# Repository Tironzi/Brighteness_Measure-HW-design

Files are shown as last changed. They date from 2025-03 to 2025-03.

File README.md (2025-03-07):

# Brighteness_Measure-HW-design
Electronics Applications Project 
Requirements: Design a light measurement circuit using a photodiode. The circuit should have a measurement range of 10-100 mW/cm², with a resolution of 5 mW/cm², and the output should be a corresponding current ranging from 4-20 mA (grounded).

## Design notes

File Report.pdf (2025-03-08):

ĐẠI HỌC QUỐC GIA TP. HỒ CHÍ MINH

TRƯỜNG ĐẠI HỌC BÁCH KHOA

KHOA ĐIỆN – ĐIỆN TỬ

BỘ MÔN ĐIỆN TỬ

---------------o0o---------------

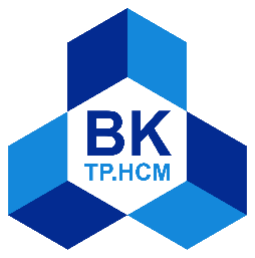
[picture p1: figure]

BÁO CÁO BÀI TẬP LỚN – PHẦN 1

ĐIỆN TỬ ỨNG DỤNG

LỚP L01 – NHÓM 9

ĐỀ TÀI:

THIẾT KẾ MẠCH ĐO ÁNH SÁNG SỬ DỤNG PHOTODIODE

BRIGHTNESS METER CIRCUIT DESIGN

Giảng viên hướng dẫn: Ths. Nguyễn Trung Hiếu

TP. HCM, tháng 12 năm 2024

SINH VIÊN THỰC HIỆN ĐỀ TÀI

Họ và tên | MSSV | Chữ ký
Lê Trung Hiếu | 2111185
Nguyễn Đức Hoàng | 2110184
Lê Viết Trọng | 2012298

LỜI CẢM ƠN

Trước tiên, nhóm chúng em xin gửi lời cảm ơn tới các quý thầy cô Khoa Điện - điện

tử của trường Đại học Bách Khoa Tp.HCM đã chỉ dạy, truyền đạt những kiến thức, kỹ

năng cần thiết để chúng em có thể thực hiện được đề tài này.

Và hơn hết, nhóm chúng em xin gửi lời cảm ơn chân thành đến thầy Nguyễn Trung

Hiếu đã tận tình chỉ dẫn, giúp đỡ chúng em trong quá trình thực hiện đề tài. Những lời

khuyên bổ ích của thầy đã giúp chúng em rất nhiều trong quá trình nghiên cứu đề tài

và giải quyết những vấn đề gặp phải để có thể hoàn thiện đề tài một cách tốt nhất.

Do kiến thức của các thành viên trong nhóm còn hạn chế nên sẽ có những sai sót trong

quá trình thực hiện đề tài. Nhóm em rất mong nhận được sự đánh giá khắt khe và góp

ý từ thầy để chúng em có thể hoàn thiện hơn nữa.

Cuối cùng, nhóm chúng em xin chúc thầy luôn luôn mạnh khỏe và ngày càng thành

công trong công việc ạ!!!

Trân trọng,

GIỚI THIỆU ĐỀ TÀI

Chúng ta có thể thấy trong thế giới ngày nay mọi thức đang dần trở nên số hóa,

mọi thức ngày càng hiện đại và văn minh hơn. Vì vậy nhắc tới thế ngày nay thì luôn

gắn liền với những cụm từ thông minh như nhà thông minh, thành phố thông minh,

máy móc thông minh. Nhưng thứ này sinh ra mục đích là để phục vụ cho đời sống của

con người chúng ta. Những thiết bị điện tử ngày càng tiên tiến và phát triển, chúng tập

trung vào sự chính xác, tốc độ phản hồi nhanh đem đến một trải nghiệm người dùng

hiệu quả, chính xác. Để có được những yêu cầu đó thì cảm biến đóng một vai trò rất

quan trọng trong các thiết bị điện tử. Từ sinh hoạt, sản xuất, hay y tế mọi lĩnh vực trong

cuộc sống này không thể thiếu thiết bị cảm biến. Chúng là hạt nhân trong thế giới hiện

đại. Cảm biến góp phần cho thế giới ngày càng trở nên linh hoạt hơn và tự động hóa

giúp nâng cao năng suất và hiệu quả. Sự xuất hiện của cảm biến đã mở ra vô vàn các

thiết bị ứng dụng vào vô vàn lĩnh vực trong đời sống. Thế nên, nhóm chúng em sẽ giới

thiệu một loại cảm biến thực hiện trong đề tài lần này là cảm biến ánh sáng. Cũng như

các loại cảm biến khác, cảm biến ánh sáng rất quan trọng trong nhiều lĩnh vực. Trong

smart home chúng điều chỉnh tự động ánh sáng trong căn phòng phù hợp với từng điều

kiện cụ thể; trong công nghiệp chúng điều chỉnh độ sáng trong các hệ thống chiếu sáng.

Trong các thiết bị điện tử như điện thoại, máy tính bảng chúng tự điều chỉnh độ sáng

màn hình giúp tiết kiệm pin, bảo vệ mắt. Vì những lợi ích trên mà cảm biến ánh sáng

mang lại nên nhóm chúng em quyết định chọn đề tài “ Thiết kế mạch đo ánh sáng sử

dụng Photodiode ”.

MỤC LỤC

e. Thiết kế mạch đọc dòng điện và cho ngõ ra ADC. Tiến hành lựa chọn ADC a. Lựa chọn và mô phỏng photodide 2 dây (có điện trở dây dẫn là 10Ω).

Để có thể đo thông số EE trong khoảng 10mW/cm² đến 100mW/cm²

, đầu tiên, cần chọn

một photodiode phù hợp. Photodiode SFH 206 K là lựa chọn lý tưởng cho mạch đo cường độ ánh sáng từ 10 mW/cm² đến 100 mW/cm² với độ phân giải 5 mW/cm² nhờ

vào các đặc tính vượt trội như dải nhạy quang phổ rộng (400 nm - 1100 nm), độ nhạy

cao R(λ)=0.62 A/W tại 850 nm, và diện tích nhạy sáng lớn 7.02 mm²
. Với thời gian đáp
ứng nhanh (20 ns) và khả năng hoạt động ổn định trong môi trường từ -40°C đến 100°C,

photodiode này đảm bảo đo chính xác cường độ ánh sáng trong phạm vi yêu cầu, đáp

ứng tốt yêu cầu từ đề tài, cùng với lợi ích đó lại giá thành rẻ.

Để tính được dòng quang điện IP, đầu tiên, chúng ta có được công thức tính Sensitivity

của photodiode như sau:

R(λ) = k ∗ S(λ)

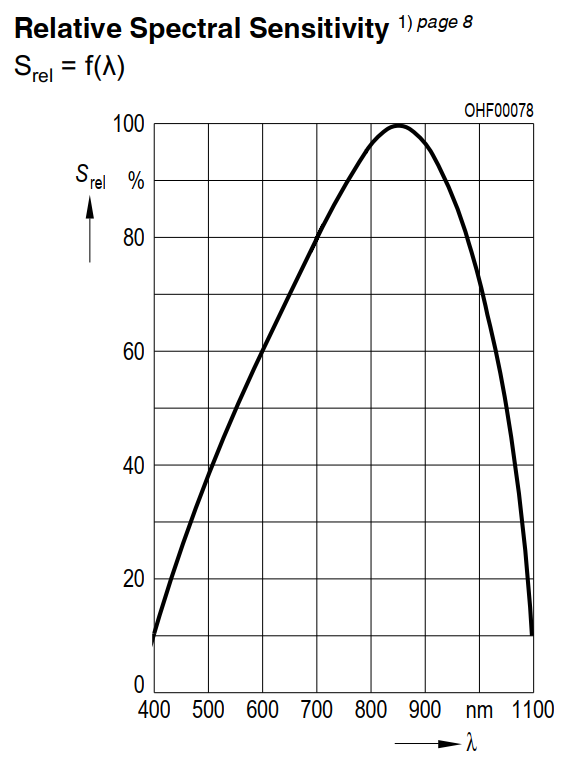
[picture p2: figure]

Dựa vào datasheet, tại λ = 850nm, ta có được R(λ) = 0.62 (A/W) = 0.62 (mA/mW) và S(λ)=1. Như vậy, hằng số k sẽ bằng 0.62. Dựa vào datasheet, lấy chuẩn tại tại λ =

550nm, S(λ)=0.5. Sau khi tính được hệ số k, dòng quang điện IP được tính như sau:

IP = R(λ) ∗ ΦE = k ∗ S(λ) ∗ EE ∗ A = 0.62 ∗ 0.5 ∗ EE ∗ (2.6 ∗ 10⁻¹

∗ 1.09 ∗ 10⁻¹
)
= 8.7854 ∗ 10⁻³
∗ EE(mA)

Do EE nằm trong khoảng 10mW/cm² đến 100mW/cm²

, nên IP sẽ nằm trong khoảng từ

0.087854 (mA) đến 0.87854 (mA). Bên cạnh đó, để tham chiếu, dựa vào khoảng giá trị

của EE, có thể tính được EV nằm trong khoảng 6.83 lm/cm² đến 68.3 lm/cm²

. Tham số

này sẽ có giá trị khi sử dụng các thiết bị Lux Meter để kiểm tra độ chói trong thực tế.

Các giá trị của EE khi đổi sang EV sẽ dựa trên bảng sau:

EE (mW/cm2) | EV (lm/cm2) | EE (mW/cm2) | EV (lm/cm2)
10 | 6.83 | 60 | 40.98
15 | 10.245 | 65 | 44.395
20 | 13.66 | 70 | 47.81
25 | 17.075 | 75 | 51.225
30 | 20.49 | 80 | 54.64
35 | 23.905 | 85 | 58.055
40 | 27.32 | 90 | 61.47
45 | 30.735 | 95 | 64.885
50 | 34.15 | 100 | 68.3

55 37.565

Trong phần mềm Multisim, SFH 206 K sẽ được mô phỏng bằng một diode có 3 cực,

ngoài hai cực Anode và Cathode thì còn có một chân P. Theo như mô tả, Trong mô hình SPICE của photodiode SFH_206_K/AD, chân P đại diện cho đầu vào ánh sáng,

được mô phỏng như một điện áp tỷ lệ với cường độ ánh sáng chiếu tới (W/cm²). Giá

trị điện áp này được sử dụng để tính dòng quang điện IP = V(P) ∗ Spec ∗ Sensy, trong

đó Spec (mặc định bằng 1.0) là thông số quang phổ và Sensy là độ nhạy của

photodiode (mặc định 0.62 A/W). Chân P cũng hỗ trợ mô phỏng các đặc tính động như

rise time và fall time qua các linh kiện R và C. Để có thể mô phỏng giá trị của IP dựa

trên giá trị của V(P) thì tiến thành mô phỏng photodiode trong điều kiện ngắn mạch:

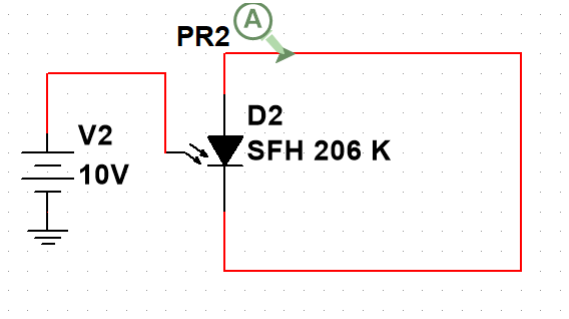
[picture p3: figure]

Khi này, dòng IP sẽ bằng dòng ngắn mạch ISC và bằng dòng từ Anode sang Cathode

IKA. Khi mô phỏng bằng Parameter Sweep cho thông số V(P), khi kiểm tra bảng số liệu

và đồ thị, có thể thấy rằng IP = V(P) ∗ 1.0 ∗ 0.62 và bên cạnh đó, có thể thấy I có giá

trị max bằng 1A khi V(P) đạt khoảng 1.6129 V do hiện tượng bão hòa dòng quang

điện, khi photodiode đã tạo ra và thu thập tối đa các cặp điện tử-lỗ trống từ ánh sáng

chiếu vào.

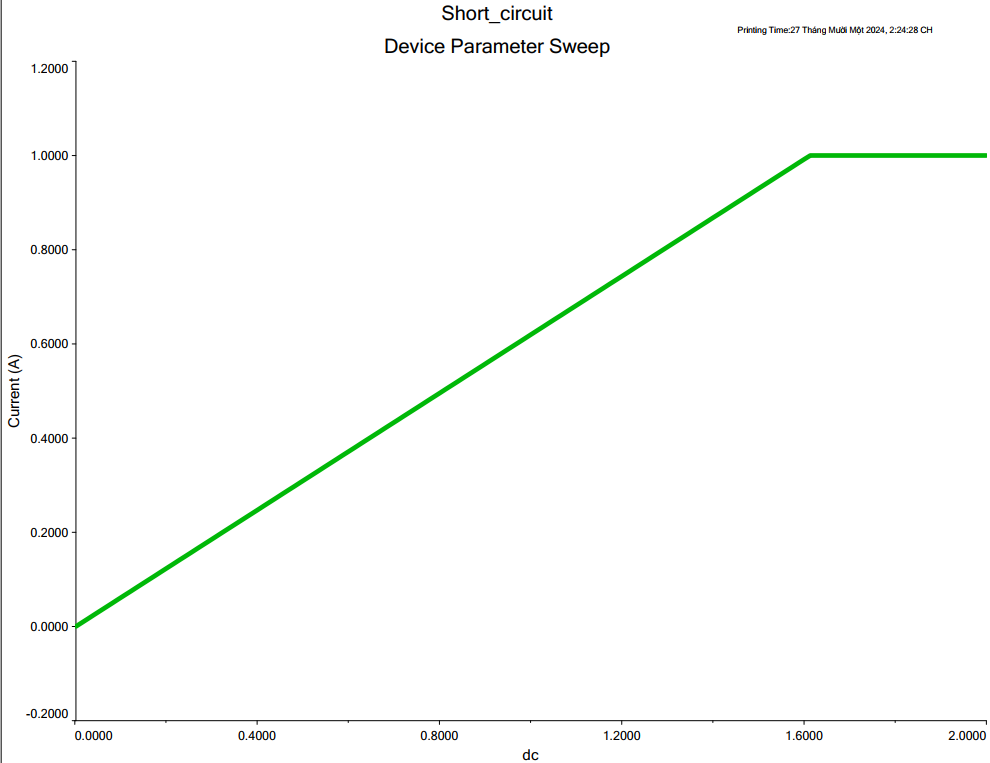
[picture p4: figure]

b. Lựa chọn mode hoạt động của photodiode:

Để giảm thiểu dòng tối của photodiode, ta sẽ vận hành photodiode trong chế độ quang

điện (photovoltaic mode) và sử dụng mạch chuyển đổi dòng sang điện áp như hình

dưới đây.

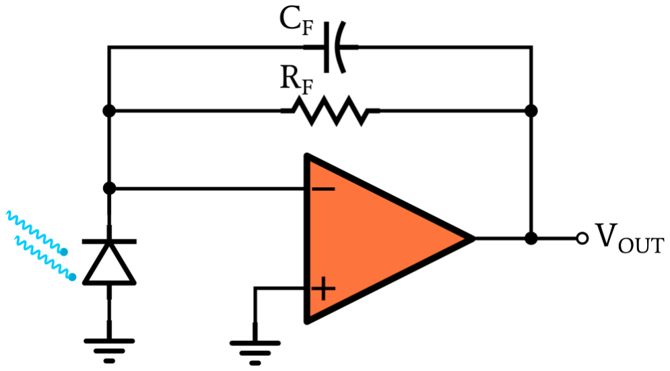
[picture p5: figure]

Như vậy, chúng ta sẽ có công thức tính điện áp DC Vout của mạch như sau:

Vout = IP ∗ RF

Trong đó, chỉ có điện trở hồi tiếp (RF) có tác dụng khuếch đại. Tụ điện (CF) được sử

dụng nhằm tránh hiện tượng dao động bằng cách bù trừ cho điện dung mạch trong của

nút photodiode, vốn tạo ra một cực (pole) trong mạng hồi tiếp. Tụ CF thực hiện bù trừ

bằng cách tạo ra một điểm zero trong mạng hồi tiếp. CF là tụ được mắc thêm để lọc

thông cao với tần số cắt fc =

1
2πRFCF

. Điều này để giảm ảnh hưởng của các điều kiện

không lý tưởng của OP-AMP.

Như vậy, chọn RF = 2.7 kOhm, lúc đó Vout = 2700*IP.

c. Lựa chọn OP-AMP sử dụng, mô phỏng OP-AMP theo datasheet:

OPA333 được chọn nhờ các đặc tính vượt trội: dòng lệch ngõ vào Iio=140 pA, dòng

thiên ngõ vào Iib=70 pA và điện áp bù ngõ vào Vio=2 μV, đảm bảo độ chính xác cao và

phù hợp cho các ứng dụng đo lường chính xác.

Tính toán sai lệch gây ra bởi Vio của OP-AMP:

∆V = ±Vio ∗ (1 +

2700
10 ) = ±540μV

Tính toán sai lệch gây ra bởi Iio và Iib:

Iib =

I+ + I−
2

= 70pA

Iio = |I+ − I−

| = 140pA

I+ = 140pA,I− = 0 ℎoặc I− = 140pA,I+ = 0

∆V = I− ∗ R− = 0.3789(μA)

Mô phỏng OP-AMP OPA333 trong Multisim bằng cách tạo một khối hierarchial

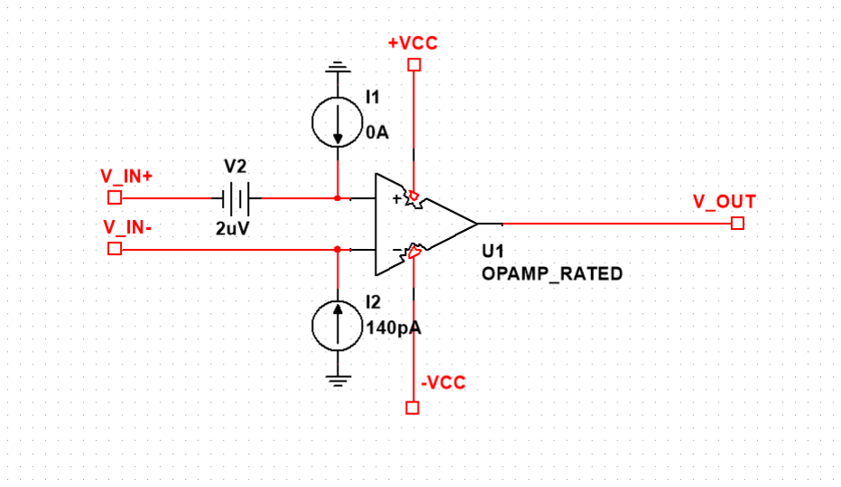
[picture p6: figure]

d. Đảm bảo sai số (giữa giá trị lý thuyết và giá trị thực tế) dưới ±5%:

Để kiểm tra Vout giữa tính toán lý thuyết và giá trị thực tế khi mô phỏng, cần lập một bảng

Excel để khảo sát giá trị phụ thuộc vào Irradiance EE:

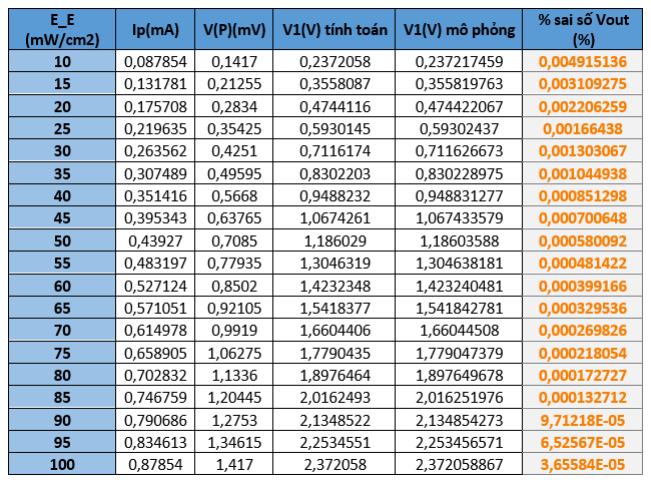
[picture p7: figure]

Với IP được tính bằng công thức đã được trình bày trong câu a, V(P) = IP/0.62, V1 theo lý

thuyết sẽ được tính bằng V1_lt=IP*2700. Giá trị V1 sẽ được mô phỏng sẽ được mô phỏng

bằng phần mềm Multisim. Sai số sẽ được tính như sau:

% sai số =

|V1 lý tℎuyết − V1 mô pℎỏng |

V1 lý tℎuyết

∗ 100%

Như vậy, dựa trên mô phỏng, sai số dưới 5% được đảm bảo.

e. Thiết kế mạch đọc dòng điện và cho ngõ ra ADC. Tiến hành lựa chọn ADC (số bit,

nguồn). Mô phỏng mạch đọc và kiểm chứng.

Đầu tiên, cần thiết kế mạch chuyển đổi từ điện áp V1 từ 0,2372058-2,372058 V sang

4-20 mA. Xây dựng phương được phương trình Iout theo V1 như sau:

Iout = 0.007494664033V1 +

1
450 (1)

Sử dụng mô hình mạch V/I:

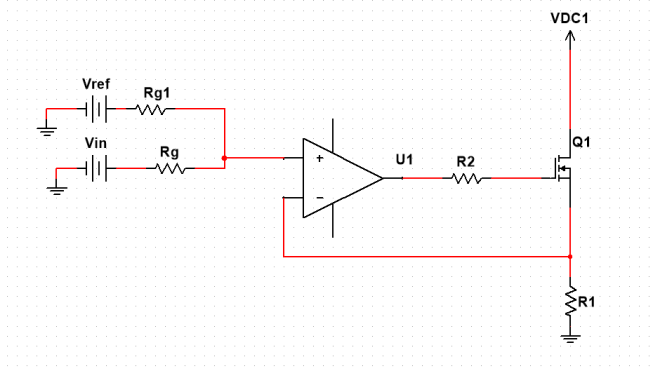
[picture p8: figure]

Iout = IR1 =

V1 + Vref
2R1

(2)

Từ (1) và (2) => Chọn R1 = 66.7 Ohm, Vref = 0.2695 V, R2 = 10 Ohm, Rg = 1kOhm. Tiến hành mô phỏng và kiểm chứng mạch:

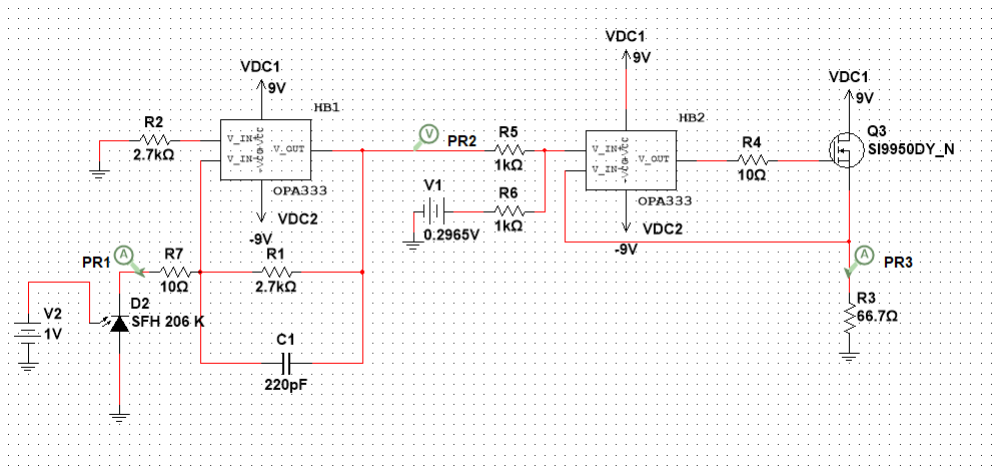
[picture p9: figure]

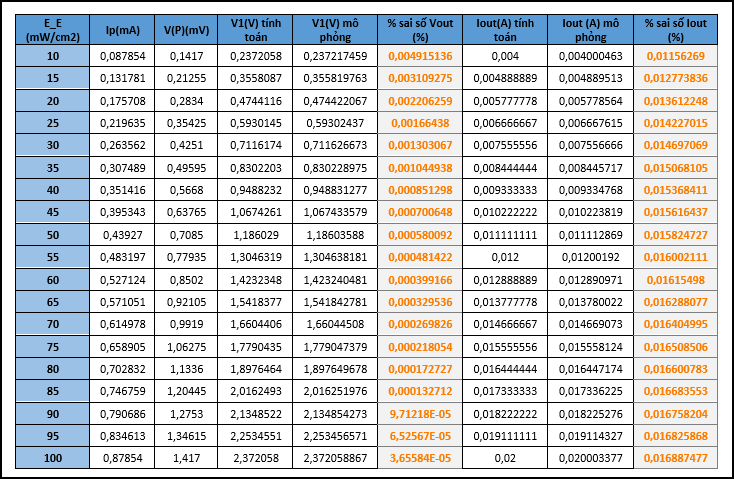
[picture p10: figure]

Biểu đồ phía trên thể hiện mối quan hệ giữa V(P) (trục hoành) và V1 (đường màu xanh

dương), Iout (đường màu xanh lá).

Thiết kế mạch đọc ADC:

Đầu tiên, để có thể đọc tín hiệu dòng điện, cần thiết kế mạch sử dụng AD8237RMZ để

khuếch đại giá trị dòng đi qua điện trở 66.7 Ohm như sau:

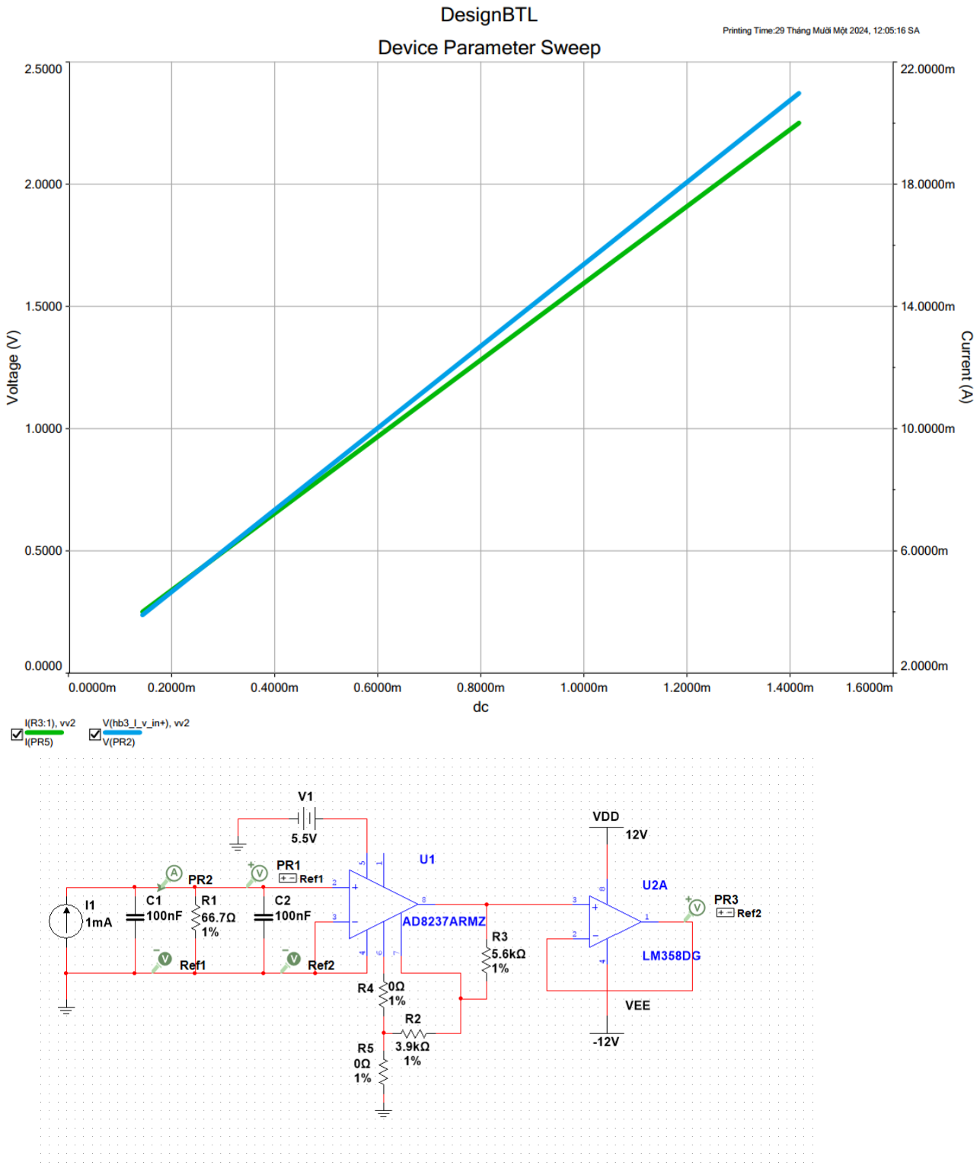
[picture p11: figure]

Như vậy, khi đi qua AD8237, Vout sẽ bằng I1 ∗ R1 ∗ (1 +
R3
R2

) = I1 ∗ 162.4736

Tiếp theo đó, cần thêm một voltage follower (hoặc buffer amplifier) trước khi đưa tín

hiệu vào ADC (Analog-to-Digital Converter) là rất quan trọng trong nhiều trường hợp

để đảm bảo tín hiệu được đo chính xác và không bị suy giảm. Đầu tiên, nó cải thiện

impedance matching, đặc biệt khi nguồn tín hiệu có impedance cao, bằng cách sử

dụng impedance đầu vào cao và impedance đầu ra thấp, giúp tránh suy giảm tín hiệu

và đảm bảo tín hiệu vào ADC không bị mất mát. Thứ hai, voltage follower giảm tải lên

nguồn tín hiệu, ngăn ngừa hiện tượng tải quá mức bởi ADC, do ADC thường có dòng

tải khá lớn ở đầu vào. Ngoài ra, voltage follower duy trì tín hiệu không biến dạng, đặc

biệt khi sử dụng với operational amplifier (op-amp), giúp giữ tín hiệu đầu vào chính

xác khi đọc qua ADC. Nó cũng giúp giảm thiểu ảnh hưởng của dòng tải, bảo vệ tín hiệu

gốc và giúp ADC nhận tín hiệu ổn định hơn. Cuối cùng, trong trường hợp tín hiệu gốc

có biên độ thấp, voltage follower giúp tăng cường tín hiệu sao cho phù hợp với phạm

vi của ADC, tăng độ chính xác và độ phân giải của phép đo.

Như vậy, sau khi gắn thêm voltage follower tại V1 (điện áp sau khi qua AD8237), mạch

đo ADC được thiết kế như sau:

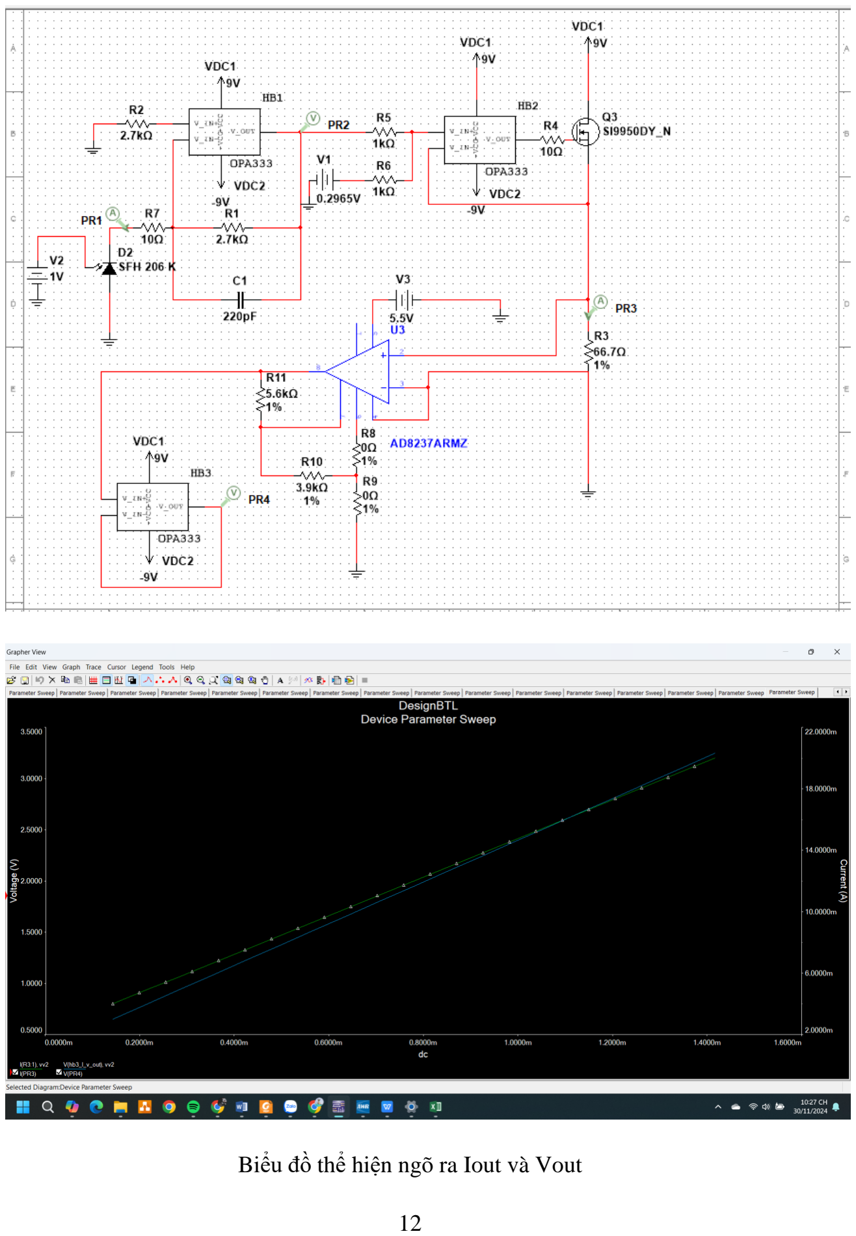
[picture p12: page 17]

Biểu đồ thể hiện ngõ ra Iout và Vout

Chọn 12 bit ADC để phù hợp với STM32. Với mức điện áp tham chiếu 3.3V, công

thức để chuyển đổi thành giá trị digital 12-bit như sau:

Digital = (

Điện áp đầu vào(V)
3.3(V)

) ∗ 4096

Như vậy, có bảng giá trị quy đổi dựa vào Vout mô phỏng như sau:

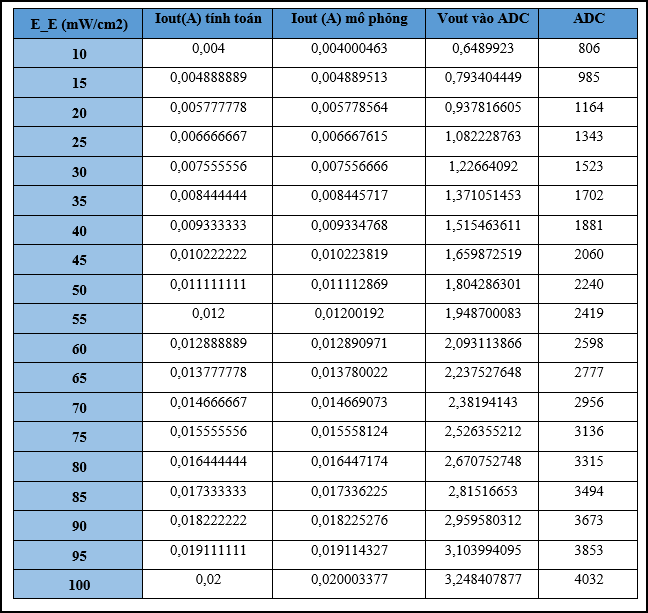
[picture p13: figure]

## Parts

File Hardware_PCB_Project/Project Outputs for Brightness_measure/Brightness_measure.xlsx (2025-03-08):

Comment | Description | Designator | Footprint | LibRef | Quantity
Test_Point | Test point, 2mm radius | -9V, +0.2965V, +5V, +9V, +12V, GND, V1, Vtrim | TP_2MM | Test_Point | 8 | v
10uF | CAP, size 0603,10uF | C1, C3 | CAP_0603 | 01060310010 | 2 | v
100nF | CAP, size 0603, 100nF | C2, C4, C9 | CAP_0603 | 01060310410 | 3 | v
22uF | V-Chip, D4 x H5.5mm, 22uF, 16V | C5 | WCAP-ASLI_D4H5.5 | 865080340003 | 1 | v
10uF | Dán | C6, C10 | tu nhom 4 (b) | Tu Nhom 10uF 16V | 2 | 5 | ic
1uF | CAP, size 0603, 1uF | C7, C8 | CAP_0603 | 01060310510 | 2 | v
220pF | Dán | C11 | Tu 0603 | Tu 0603 220pF 50V 10% | 1 | 10 | ic
D Schottky | Schottky Diode | D1 | SS34 | D Schottky | 1 | v
LED SMD | LED | D2, D3, D4 | LED_0805_Blue | LED SMD | 3 | 10 | ic
SFH206K | photodiode, 850nm | D5 | SFH206K | SFH206K | 1 | v
16V, 2.5A | Resettable Fuse, Size 1812, 8V, 2A | F1 | Fuse_SMD_1812 | 061812200008 | 1 | 1 | ic
Jac DC | Jac DC input | JDC1 | DC0 | DCIN | 1 | v
LN2302LT1G | SOT-23-3, MOSFET kênh N, 20V, 2.3A | Q1 | SOT95P240X120-3N | MOSFET | 1 | 2 | ic
5.6k | RES, 5.6k Ohm, size 0603, 1% | R1, R2, R5 | resistor_0603 | 0006035621 | 3 | v
1k | Dán | R3, R9 | tro smd 0603 | Tro 0603 1% 1k | 2 | v
2.7k | dán | R4, R12 | TRO SMD 0603 | tro 0603 5% 2.7k | 2 | 50 | ic
162k | Dán | R6 | TRO SMD 0603 | Tro 0603 1% 162k | 1 | 50 | ic
10.2k | Dán | R7 | TRO SMD 0603 | tro 0603 1% 10.2k | 1 | 50 | ic
12R | Dán | R8 | Tro SMD 0805 | tro 0805 1% 12R | 1 | 50 | shop
10R | Dán | R10, R11 | Tro smd 0603 | Tro 0603 1% 10R | 2 | 50 | ic
62R | Dán | R13 | TRO SMD 0603 | Tro 0603 1% 62R | 1 | 50 | shop
4.7R | Dán | R14 | TRO SMD 0603 | Tro 0603 1% 4.7R | 1 | 50 | ic
5.6k | Dán | R15 | TRO SMD 0603 | Tro 0603 1% 5.6k | 1 | v
0R | Dán | R16, R18, R19, R20 | tro smd 0603 | Tro 0603 1% 0R | 4 | v
3.9k | Dán | R17 | Tro SMD 0805 | Tro 0603 5% 3.9k | 1 | 50 | ic
AMS1117-5V | AMS1117-5V, OUT 5V 1A. | U1 | AMS1117-5V SOT223 | AMS1117-5V | 1 | 2 | ic
ICL7662CBA-T |  | U2 | SOP 8 | ICL7662CBA-T | 1 | 1 | shop
78L09 | 78L09, OUT 9V, 0.1A | U3 | SOT89 | 78L09 | 1 | 1 | ic
OPA188AIDR | Precision, Low-Noise, Rail-to-Rail Output, 36V Zero-Drift Operational Amplifier 8-SOIC -40 to 125 | U4, U5, U6 | SOIC127P599X175-8N | OPA188AIDR | 3 | v
AD8237ARMZ | Micropower, Zero Drift, True Rail-to-Rail Instrumentation Amplifier | U7 | AD8237ARMZ | AD8237ARMZ | 1 | v
JP 1x1 2.54 | Cắm | V2 | JP 1x1 DT | JP 1x1 2.54 Duc Cong | 1 | v
3362P-1-503 | 50 kOhms 0.5W, 1/2W PC Pins Through Hole Trimmer Potentiometer Cermet 1 Turn Top Finger Adjustment | VR1 | TRIM_3362P-1-503 | 3362P-1-503 | 1 | 2 | ic

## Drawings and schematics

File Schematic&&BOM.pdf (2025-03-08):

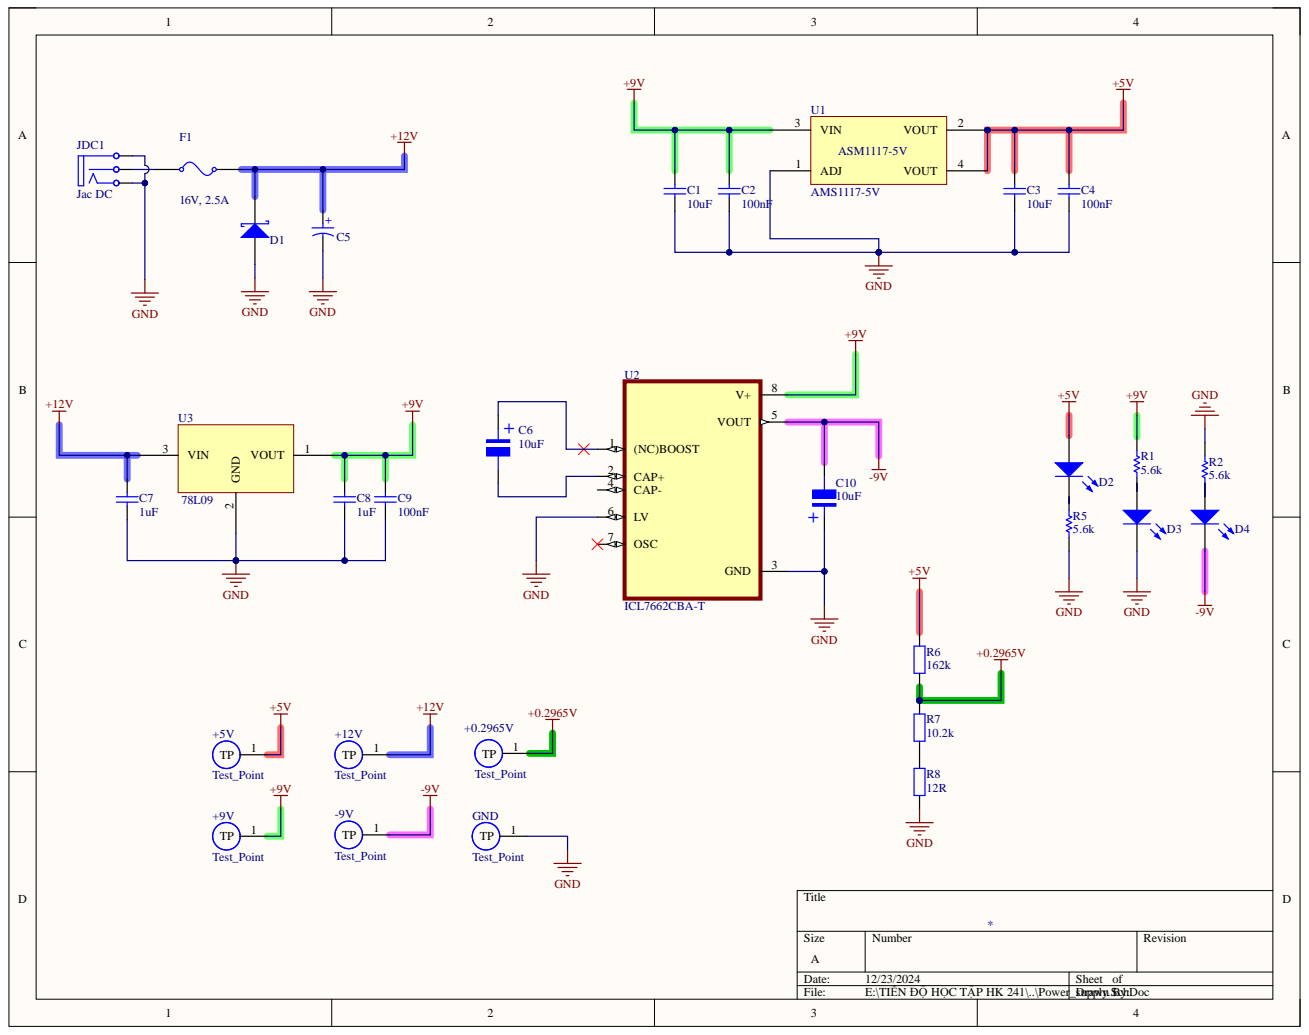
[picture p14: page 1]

CAP- 4

OSC 7

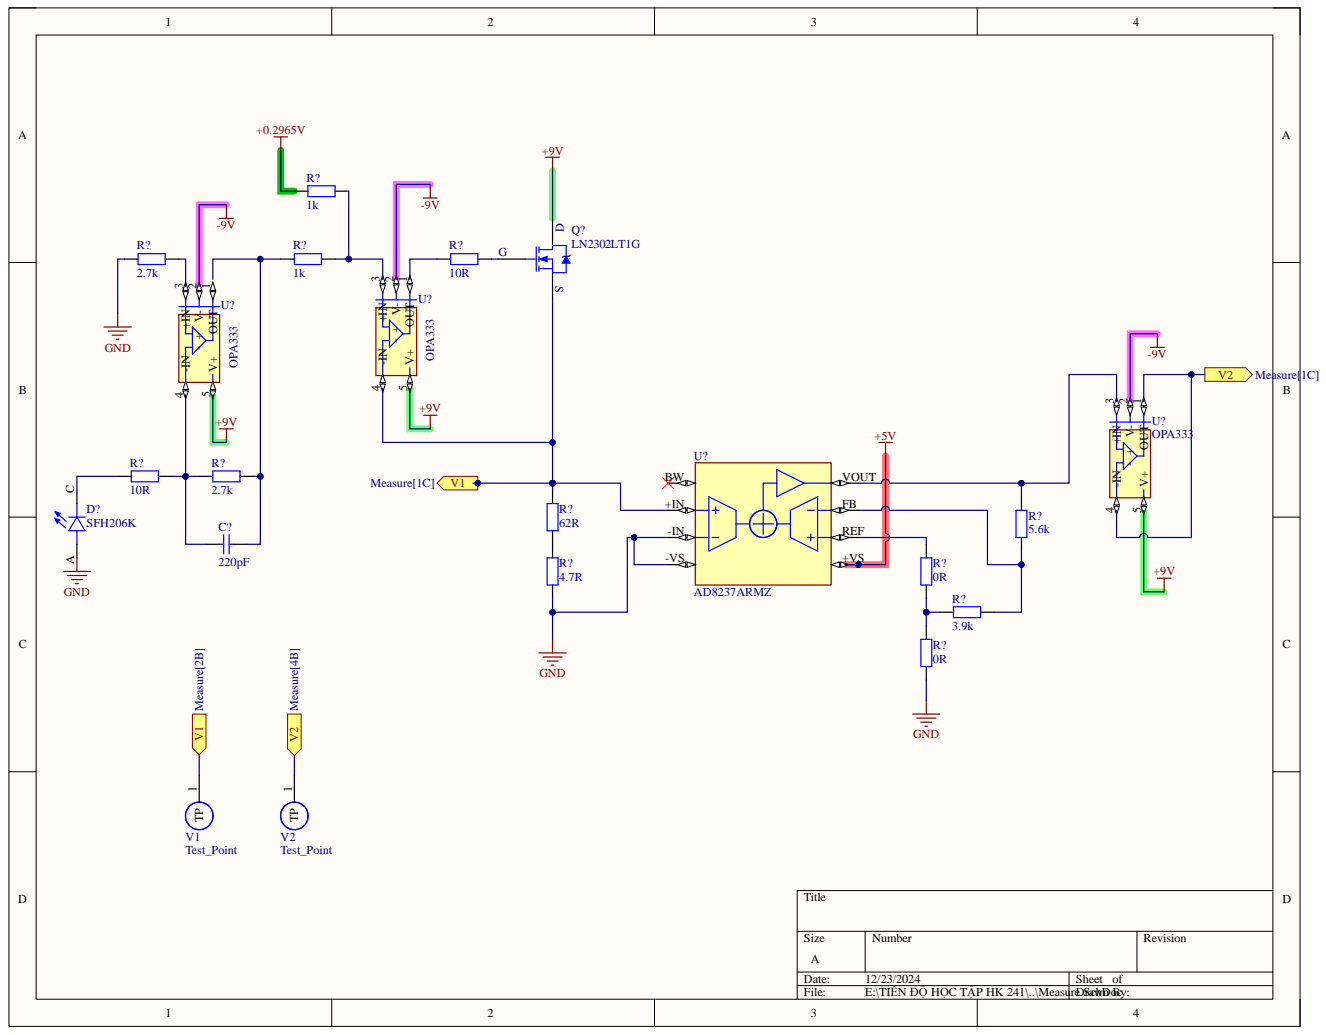
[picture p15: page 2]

REF

Comment | Description | Designator | Footprint | LibRef | Quantity
Test_Point | Test point, 2mm radius | -9V, +0.2965V, +5V, +9V, +12V, GND, V1, V2 | TP_2MM | Test_Point | 8
10uF | CAP, size 0603,10uF | C1, C3 | CAP_0603 | 01060310010 | 2
100nF | CAP, size 0603, 100nF | C2, C4, C9 | CAP_0603 | 01060310410 | 3
22uF | V-Chip, D4 x H5.5mm, 22uF, 16V | C5 | WCAP-ASLI_D4H5.5 | 865080340003 | 1
10uF | Dán | C6, C10 | tu nhom 4 (b) | Tu Nhom 10uF 16V | 2
1uF | CAP, size 0603, 1uF | C7, C8 | CAP_0603 | 01060310510 | 2
220pF | Dán | C? | Tu 0603 | Tu 0603 220pF 50V 10% | 1
D Schottky | Schottky Diode | D1 | SS34 | D Schottky | 1
LED SMD | LED | D2, D3, D4 | LED_0805_Blue | LED SMD | 3
SFH206K | photodiode, 850nm | D? | SFH206K | SFH206K | 1
16V, 2.5A | Resettable Fuse, Size 1812, 8V, 2A | F1 | Fuse_SMD_1812 | 061812200008 | 1
Jac DC | Jac DC input | JDC1 | DC0 | DCIN | 1
LN2302LT1G | SOT-23-3, MOSFET kênh N, 20V, 2.3A | Q? | SOT95P240X120-3N | MOSFET | 1
5.6k | RES, 5.6k Ohm, size 0603, 1% | R1, R2, R5 | resistor_0603 | 0006035621 | 3
162k | Dán | R6 | TRO SMD 0603 | Tro 0603 1% 162k | 1
10.2k | Dán | R7 | TRO SMD 0603 | tro 0603 1% 10.2k | 1
12R | Dán | R8 | Tro SMD 0805 | tro 0805 1% 12R | 1
0R | Dán | R? | tro smd 0603 | Tro 0603 1% 0R | 2
1k | Dán | R? | tro smd 0603 | Tro 0603 1% 1k | 2
2.7k | dán | R? | TRO SMD 0603 | tro 0603 5% 2.7k | 2
3.9k | Dán | R? | Tro SMD 0805 | Tro 0805 1% 3.9k | 1
4.7R | Dán | R? | TRO SMD 0603 | Tro 0603 1% 4.7R | 1
5.6k | Dán | R? | TRO SMD 0603 | Tro 0603 1% 5.6k | 1
10R | Dán | R? | Tro smd 0603 | Tro 0603 5% 10R | 2
62R | Dán | R? | TRO SMD 0603 | Tro 0603 1% 62R | 1
AMS1117-5V | AMS1117-5V, OUT 5V 1A. | U1 | AMS1117-3.3V SOT223 | AMS1117-5V | 1
ICL7662CBA-T | | U2 | SOP 8 | ICL7662CBA-T | 1
78L09 | 78L09, OUT 9V, 0.1A | U3 | SOT89 | 78L09 | 1
AD8237ARMZ | Micropower, Zero Drift, True Rail-to-Rail Instrumentation Amplifier | U? | AD8237ARMZ | AD8237ARMZ | 1
OPA333 | Op Amp Single Low Offset Voltage Amplifier R-R I/O Â±2.75V/5.5V 8-Pin SOIC Tube | U? | SOT23-5 | OPA333 | 3
